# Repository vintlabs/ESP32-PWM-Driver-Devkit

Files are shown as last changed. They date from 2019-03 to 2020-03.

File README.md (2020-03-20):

# ESP32-PWM-Driver-Devkit
## ESP32 Development kit with 8 PWM outputs that can be driven at 5-15V at up to 2A each

### Board and Pinout:
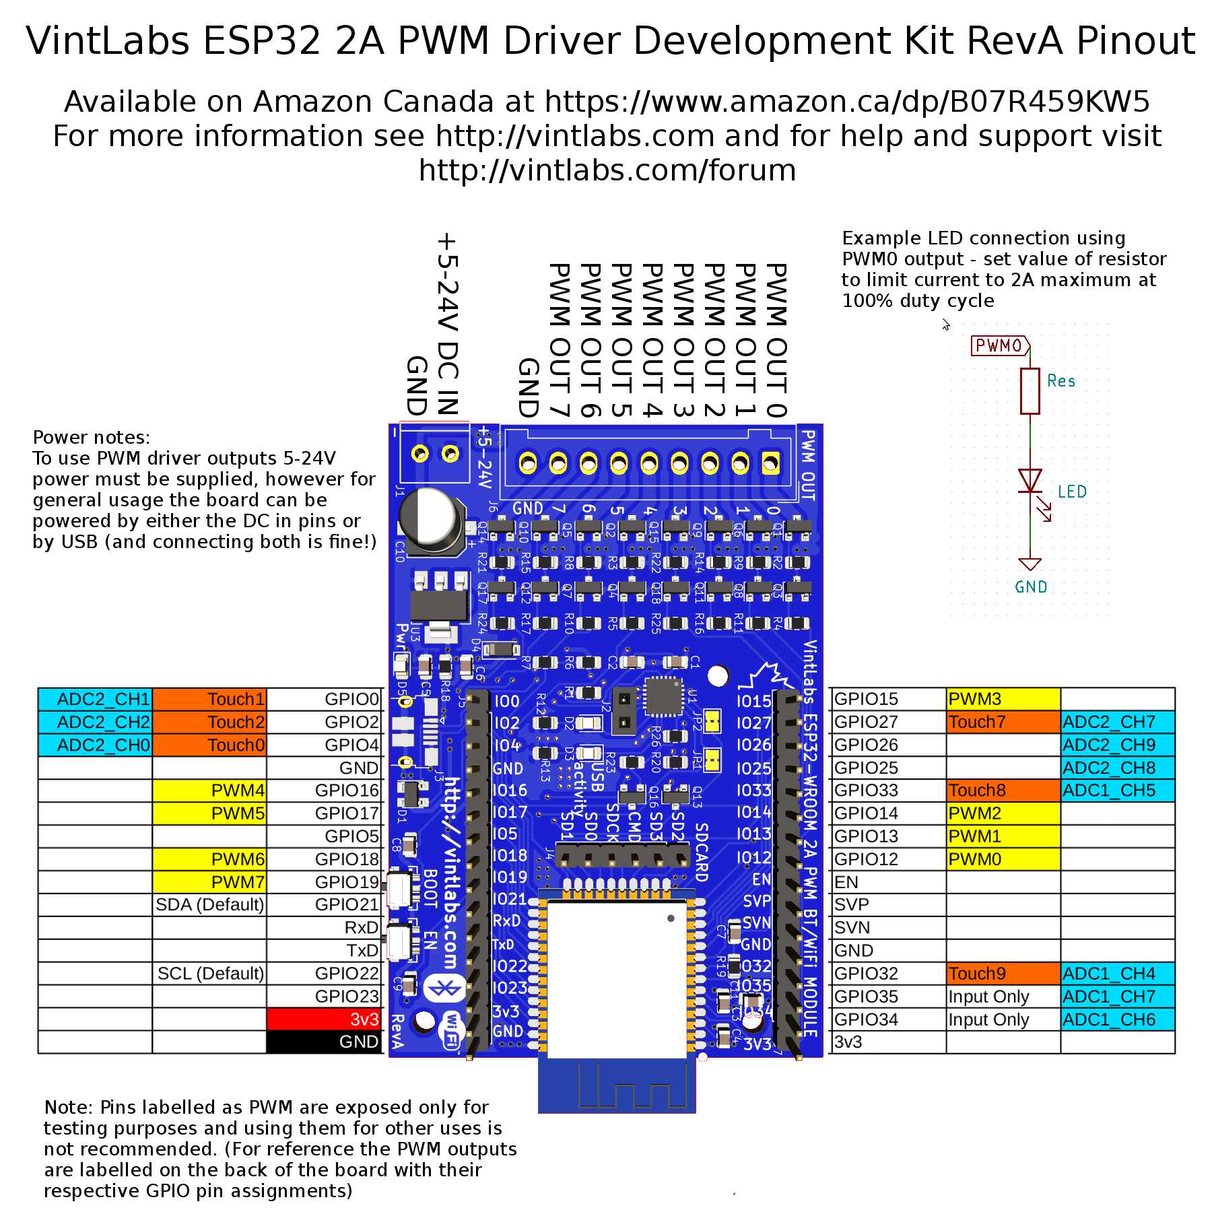
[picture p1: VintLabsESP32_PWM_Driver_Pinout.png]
Board Top and Pinout


The PWM driver board is powered by an ESP32 and features 8 PWM outputs that can power LED lighting at 5-15V at up to 2A each. It can also be used as a general-purpose ESP32 development kit.

The primary purpose of the design is to control LED lighting (like these: https://www.amazon.ca/gp/product/B00QN4X5MM/ref=ppx_yo_dt_b_search_asin_title?ie=UTF8&psc=1  I am not affiliated with this seller, but the LED strips are great!), however there may be many other uses, like controlling DC motors! The board can be powered by either USB or by connecting 5-15V to the power input connector (connecting both is fine!), however do note that to use the PWM outputs an external power source is strongly recommended, as otherwise it will try to use the power from the USB bus and likely would cause power/stability issues.

### Schematic:
RevA: https://github.com/vintlabs/ESP32-PWM-Driver-Devkit/raw/master/ESP32-PWM-Driver-Devkit-RevA-schematic.pdf
RevB: https://github.com/vintlabs/ESP32-PWM-Driver-Devkit/raw/master/ESP32-PWM-Driver-Devkit-RevB-schematic.pdf

### Connecting via USB
#### Linux
If the device is not detected, you may need to add `CONFIG_USB_SERIAL_CP210X=m` to your kernel config:
```
Device Drivers --->
	USB Support --->
		USB Serial Converter Support --->
			<M>   USB CP210x family of UART Bridge Controllers  
```

If it's detected, you should see the following in /var/log/messages (may be syslog or other file depending on your distro):
```
Dec 31 17:57:51 nautilus kernel: usb 1-2.4: new full-speed USB device number 35 using ehci-pci
Dec 31 17:57:51 nautilus kernel: usb 1-2.4: New USB device found, idVendor=10c4, idProduct=ea60, bcdDevice= 1.00
Dec 31 17:57:51 nautilus kernel: usb 1-2.4: New USB device strings: Mfr=1, Product=2, SerialNumber=3
Dec 31 17:57:51 nautilus kernel: usb 1-2.4: Product: CP2102N USB to UART Bridge Controller
Dec 31 17:57:51 nautilus kernel: usb 1-2.4: Manufacturer: VintLabs
Dec 31 17:57:51 nautilus kernel: usb 1-2.4: SerialNumber: 0002
Dec 31 17:57:51 nautilus kernel: cp210x 1-2.4:1.0: cp210x converter detected
Dec 31 17:57:51 nautilus kernel: usb 1-2.4: cp210x converter now attached to ttyUSB0
```

#### Windows
See https://www.silabs.com/products/development-tools/software/usb-to-uart-bridge-vcp-drivers

### Usage in Arduino environment
To use with Arduino, ensure that you have ESP32 boards added (if you have not, see https://randomnerdtutorials.com/installing-the-esp32-board-in-arduino-ide-windows-instructions/ for some good instructions), and then select **VintLabs ESP32 DevKit** in *Tools->Board*. (If you do not see it in the list, please make sure that the ESP32 core is updated)

Example code: `git clone https://github.com/vintlabs/VintLabs-PWM-Arduino-Basic-Example.git`
```
// PWM Example for VintLabs ESP32 PWM Driver DevKit
// Connect an LED light from PWM0 on the board to ground (if using a discrete LED use a current limiting series resistor!)

// Select the PWM output to use - you can use PWM0-PWM7 for the VintLabs boards, or simply specify the GPIO number
const int pwmOutput = PWM0;

// Set the PWM frequency
const int frequency = 10000;

// Set the LED channel. Note that this is not related to a pin number, but an arbitrary channel number from 0-7
const int ledChannel = 0;

// Set the resolution. This can be 8, 10, 12 or 15 bits
const int resolution = 12;

void setup() {
  // Basic PWM setup
  ledcSetup(ledChannel, frequency, resolution);

  // Attach the actual output to the channel
  ledcAttachPin(pwmOutput, ledChannel);

}

void loop() {
  // Just loop from off to max, then back again
  for (int dc = 0; dc < pow(2, resolution); dc++)
  {
    // set the duty cycle
    ledcWrite(ledChannel, dc);
    delay(10);
  }
  for (int dc = pow(2, resolution) - 1; dc >= 0; dc--)
  {
    // set the duty cycle
    ledcWrite(ledChannel, dc);
    delay(10);
  }
}
```

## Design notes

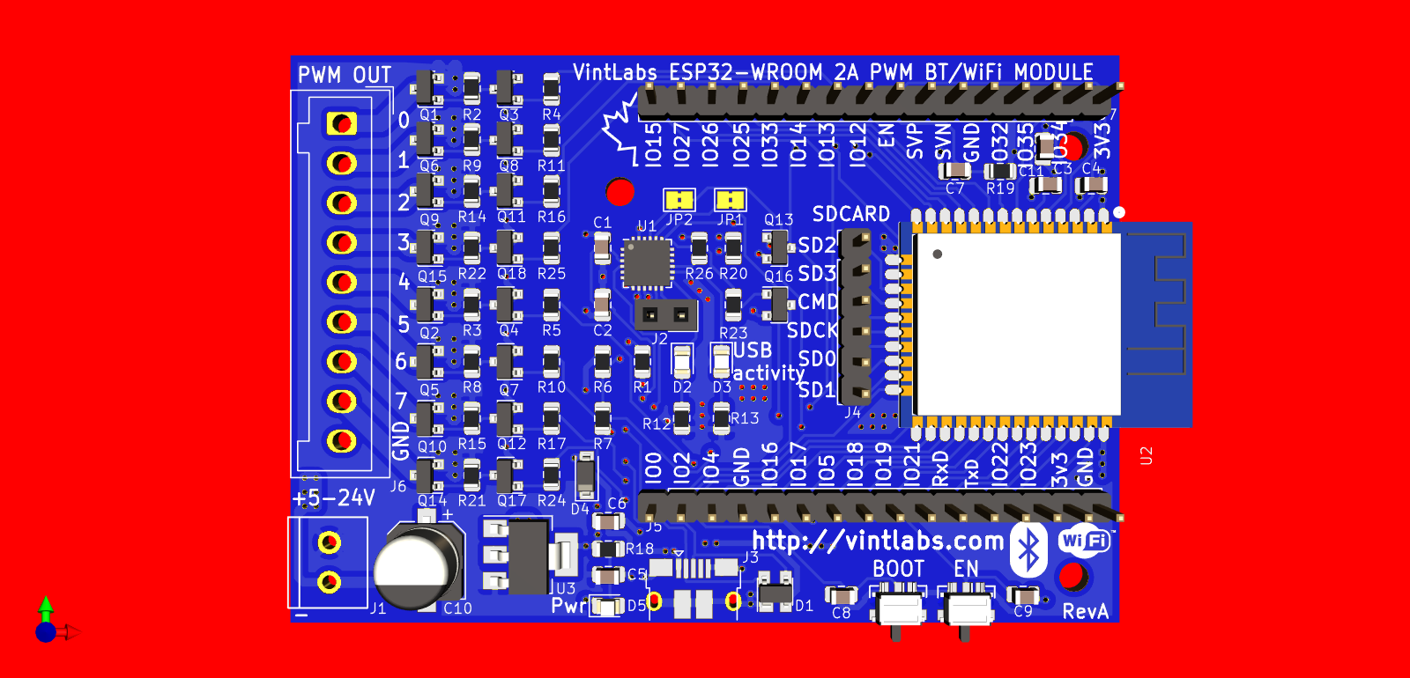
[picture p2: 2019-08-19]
3dview.png

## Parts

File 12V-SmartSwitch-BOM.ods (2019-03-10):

Source: | /home/pvint/Electronics/12V-SmartSwitch/12V-SmartSwitch.sch
Date: | Wed 20 Feb 2019 06:44:30 PM EST |  |  |  |  |  | Total BOM: | 22.115
Tool: | Eeschema 5.0.1
Generator: | /usr/share/kicad/plugins/bom_csv_grouped_by_value_with_fp.py
Component Count: | 74
Ref | Qnty | Value | Cmp name | Footprint | Description | Vendor | Cost Ea | Ext Cost
C2, C8, C9, C7, C4, | 4 | 0.1u | C | Capacitor_SMD:C_0805_2012Metric | Unpolarized capacitor |  | 0.07 | 0.28
C6, C5, C3, C1, C11, | 5 | 10u | C | Capacitor_SMD:C_0805_2012Metric | Unpolarized capacitor |  | 0.048 | 0.24
C10, | 1 | 47u | CP | Capacitor_SMD:CP_Elec_6.3x5.9 | Polarized capacitor |  | 0.3 | 0.3
D1, | 1 | SP0503BAHT | SP0503BAHT | Package_TO_SOT_SMD:SOT-143 | TVS Diode Array, 5.5V Standoff, 3 Channels, SOT-143 package |  | 1.14 | 1.14
D2, D5, D3, | 3 | LED | LED | LED_SMD:LED_0805_2012Metric | Light emitting diode |  | 0.25 | 0.75
D4, | 1 | 1N5819 | 1N5819 | Diode_SMD:D_SOD-123 | 40V 1A Schottky Barrier Rectifier Diode, DO-41 |  | 0.515 | 0.515
J1, | 1 | Screw_Terminal_01x02 | Screw_Terminal_01x02 | 12V-SmartSwitch:SCREW TERMINAL BLOCK 3.5MM 2POS | Generic screw terminal, single row, 01x02, script generated (kicad-library-utils/schlib/autogen/connector/) |  | 0.4 | 0.4
J2, | 1 | Conn_01x02_Male | Conn_01x02_Male | Connector_PinSocket_2.54mm:PinSocket_1x02_P2.54mm_Vertical | Generic connector, single row, 01x02, script generated (kicad-library-utils/schlib/autogen/connector/) |  | 0.05 | 0.05
J3, | 1 | USB_B_Micro | USB_B_Micro | 12V-SmartSwitch:USB_Micro-B_Amphenol_10118194-0001LF_Horizontal | USB Micro Type B connector |  | 0.5 | 0.5
J4, | 1 | Conn_01x06_Male | Conn_01x06_Male | Connector_PinHeader_2.54mm:PinHeader_1x06_P2.54mm_Vertical | Generic connector, single row, 01x06, script generated (kicad-library-utils/schlib/autogen/connector/) |  | 0 | 0
J5, J7, | 2 | Conn_01x16_Male | Conn_01x16_Male | Connector_PinHeader_2.54mm:PinHeader_1x16_P2.54mm_Vertical | Generic connector, single row, 01x16, script generated (kicad-library-utils/schlib/autogen/connector/) |  | 0.3 | 0.6
J6, | 1 | Conn_01x09_Male | Conn_01x09_Male | Connector_Wago:Wago_734-139_1x09_P3.50mm_Vertical | Generic connector, single row, 01x09, script generated (kicad-library-utils/schlib/autogen/connector/) |  | 1.96 | 1.96
JP1, JP2, | 2 | SolderJumper_2_Bridged | SolderJumper_2_Bridged | Jumper:SolderJumper-2_P1.3mm_Bridged2Bar_Pad1.0x1.5mm | Solder Jumper, 2-pole, closed/bridged |  |  | 0
Q2, Q1, Q6, Q5, Q10, Q9, Q15, Q14, | 8 | DMG2305UX | IRLML6402 | Package_TO_SOT_SMD:SOT-23 | -3.7A Id, -20V Vds, P-channel MOSFET, 65mOhm Rds, SOT-23 |  | 0.53 | 4.24
Q13, Q16, Q4, Q3, Q8, Q7, Q12, Q11, Q18, Q17, | 10 | MMBT2222A | BC817 | Package_TO_SOT_SMD:SOT-23 | 0.8A Ic, 45V Vce, NPN Transistor, SOT-23 |  | 0.076 | 0.76
R1, R2, R3, R8, R9, R14, R15, R21, R22, | 2 | 1k | R | Resistor_SMD:R_0805_2012Metric | Resistor |  | 0.01 | 0.02
R6, | 1 | 22.1k | R | Resistor_SMD:R_0805_2012Metric | Resistor |  | 0.01 | 0.01
R7, | 1 | 47.5k | R | Resistor_SMD:R_0805_2012Metric | Resistor |  | 0.01 | 0.01
R12, R18, R13, | 3 | 2.2k | R | Resistor_SMD:R_0805_2012Metric | Resistor |  | 0.01 | 0.03
R5, R20, R23, R19, R4, R11, R10, R17, R16, R25, R24, R26, | 19 | 10k | R | Resistor_SMD:R_0805_2012Metric | Resistor |  | 0.01 | 0.19
SW1, SW2, | 2 | SW_Push | SW_Push | 12V-SmartSwitch:SW_TACTILE_PO21301 | Push button switch, generic, two pins |  | 0.42 | 0.84
U1, | 1 | CP2102N-A01-GQFN24 | CP2102N-A01-GQFN24 | Package_DFN_QFN:QFN-24-1EP_4x4mm_P0.5mm_EP2.6x2.6mm | USB to UART master bridge |  | 2.04 | 2.04
U2, | 1 | ESP32-WROOM-32 | ESP32-WROOM-32 | 12V-SmartSwitch:ESP32-WROOM-32-Espressif-Symbol-Kicad-62379 |  |  | 6.79 | 6.79
U3, | 1 | AP1117-33 | AP1117-33 | Package_TO_SOT_SMD:SOT-223-3_TabPin2 | 1A Low Dropout regulator, positive, 3.3V fixed output, SOT-223 |  | 0.45 | 0.45
 |  |  |  |  |  |  |  | 0
 |  |  |  |  |  |  |  | 0

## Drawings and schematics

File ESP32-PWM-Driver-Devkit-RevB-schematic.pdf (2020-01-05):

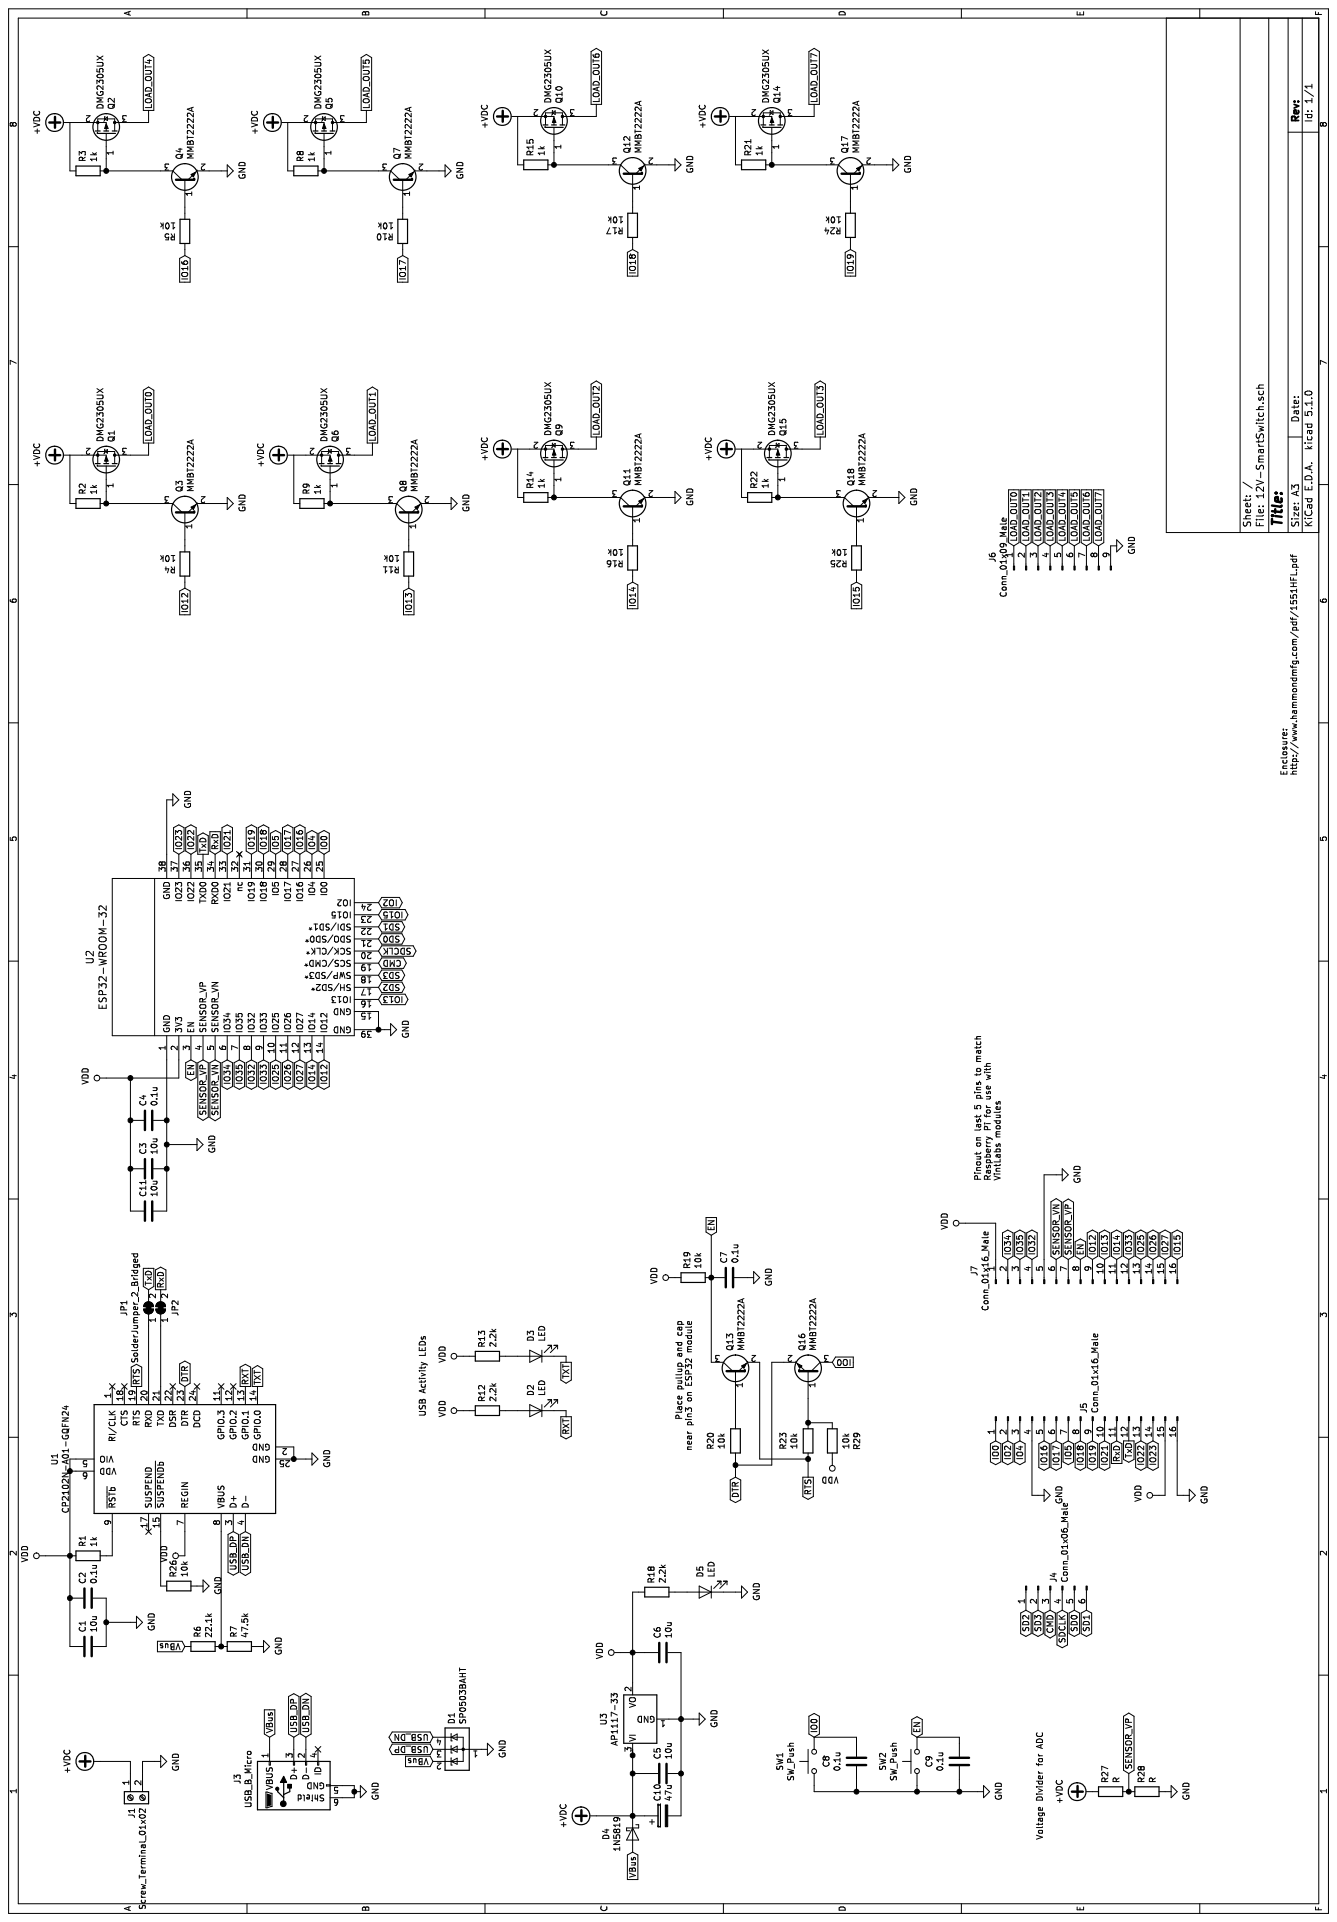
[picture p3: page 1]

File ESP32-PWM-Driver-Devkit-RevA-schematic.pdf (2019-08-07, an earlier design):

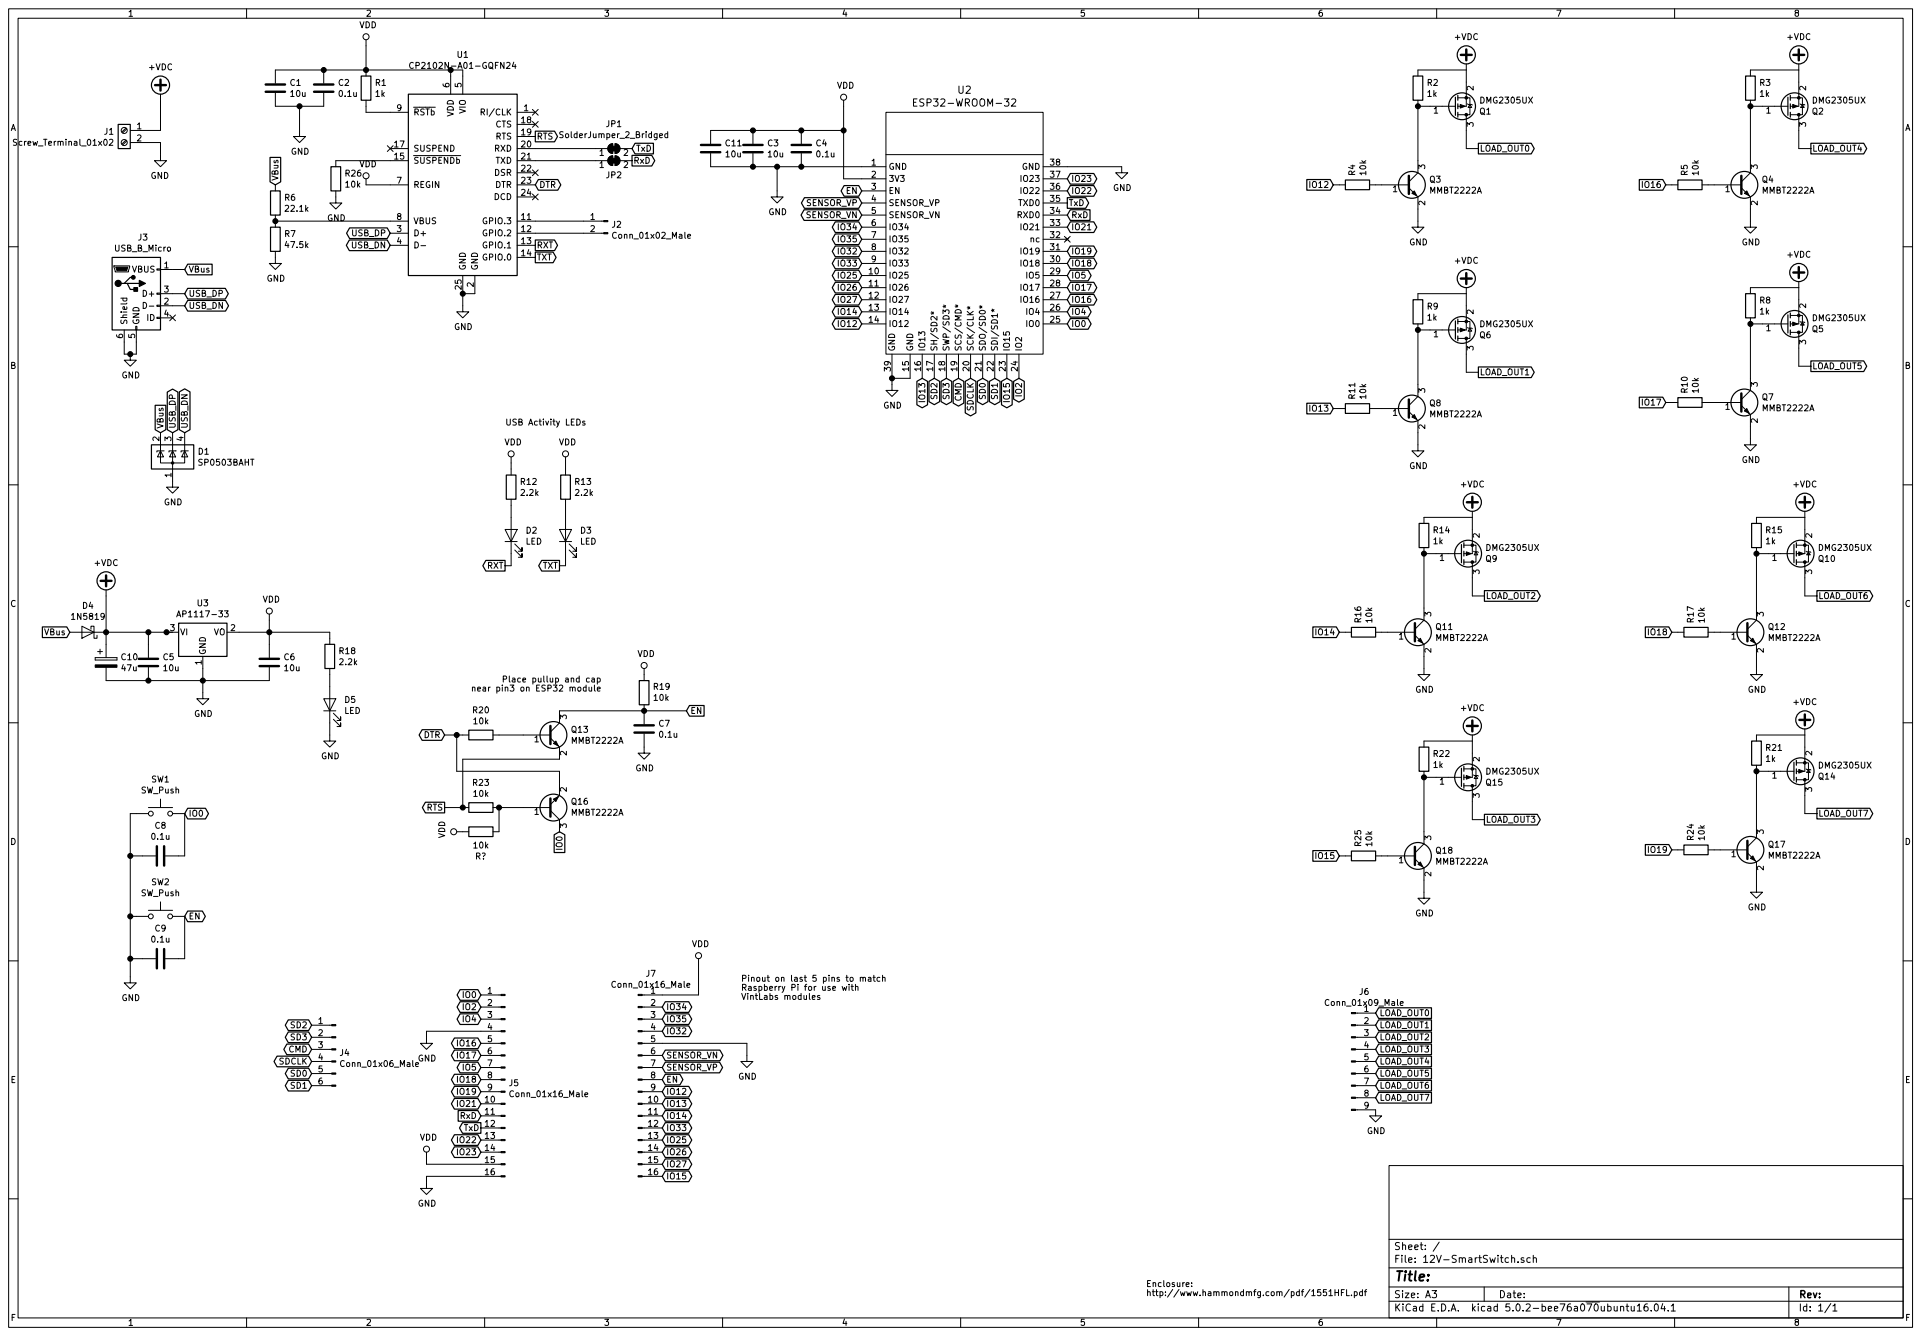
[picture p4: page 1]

6 REGIN 7 VBUS 8 RSTb 9 U1 CP2102N-A01-GQFN24 VBUS 1 D- 2 D+ 3
IO16 +VDC

2 RXD 20 TXD 21 DSR 22 DTR 23 DCD 24 GND 25 D+ 3 D- 4 VIO

Place pullup and cap
near pin3 on ESP32 module

Raspberry Pi for use with VintLabs modules R19

Pinout on last 5 pins to match

Id: 1/1 Title: File: 12V-SmartSwitch.sch Sheet: /

Enclosure: http://www.hammondmfg.com/pdf/1551HFL.pdf

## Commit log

2019-02-16 Initial Import
    [12V-SmartSwitch.kicad_pcb, 12V-SmartSwitch.sch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]
2019-03-10 Changed pullup to 1k on FETs, added pullup on IO0 BJT
    [12V-SmartSwitch.sch]
2019-03-10 Add BOM
    [12V-SmartSwitch-BOM.ods]
2019-07-23 Removed spurious trace protruding from pin 5 of USB (#12)
    [12V-SmartSwitch.kicad_pcb]
2019-08-19 Added pads for voltage divider for sensing +12v (#9)
    [12V-SmartSwitch.kicad_pcb, 12V-SmartSwitch.sch]
2019-08-19 Removed GPIO header for CP2102, fix solder mask exp. on CP2102 (#10)
    [12V-SmartSwitch.kicad_pcb, 12V-SmartSwitch.sch]
2019-08-19 Minor silk edits
    [12V-SmartSwitch.kicad_pcb]
2019-08-19 Edit traces on USB conn
    [12V-SmartSwitch.kicad_pcb]
2020-01-05 Updated schematic PDFs
